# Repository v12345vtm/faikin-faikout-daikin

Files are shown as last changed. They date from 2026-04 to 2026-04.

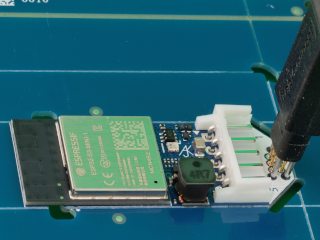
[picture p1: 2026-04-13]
releaseBinaries/Faikout.png

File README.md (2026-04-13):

# faikin-faikout-daikin
ESP32 dev board S1 mode

## 1. Install esptool.py (Windows 10)

**Prerequisites:** Python 3.7+ with pip installed

1. **Open Command Prompt as Administrator**
2. **Install:**
   ```bash
   pip install esptool
   ```
   *Or if needed:*
   ```bash
   python -m pip install esptool
   ```
3. **Test installation:**
   ```bash
   esptool version
   ```
   *Expected: `esptool.py v4.7` (or similar)*

**If "command not found":**
- Add Python Scripts folder to PATH:
  - `C:\Python39\Scripts` or `%APPDATA%\Python\Python39\Scripts`
  - System Properties → Environment Variables → Path → Edit → New → Add path → OK
  - Restart Command Prompt

## 2. Flash Faikout S1 Firmware

1. **Download release binaries** to a folder (all 4 `.bin` files):
   - `Faikout-S1-bootloader.bin`
   - `Faikout-S1-partition-table.bin`
   - `Faikout-S1-ota_data_initial.bin`
   - `Faikout-S1.bin`

2. **Navigate to that folder**:
   - Hold `Shift` + right-click in folder
   - "Open PowerShell window here" (or "Open command window here")
   - Type `cmd` and Enter

3. **Connect ESP32 dev board** to USB (check COM port in Device Manager)

4. **Put board in flash mode**:
   - Hold BOOT button
   - Press and release RESET button  
   - Release BOOT button

5. **Flash firmware** (replace COM3 with your port):
   ```bash
   python -m esptool -p COM3 write_flash ^
   0x1000 Faikout-S1-bootloader.bin ^
   0x8000 Faikout-S1-partition-table.bin ^
   0xD000 Faikout-S1-ota_data_initial.bin ^
   0x10000 Faikout-S1.bin
   ```

6. **Home Assistant**:
   - use the official integration Daikin for the faikin-faikout
   - or esphome alternative = https://github.com/joshbenner/esphome-daikin-s21 where the mosfets will not be needed but has some less features
 
7. **S10 portt**:
   - set rx tc in the esp32 webinterface
   - the original board uses fets to drive the S10 port ( maybe its inverted ?)
   - The physical interface is basic serial data, low is 0, high is 1. However the Daikin appears to operate with a 5V internal pull up on Tx and Rx lines, and a pull down. The Faikout uses a FET each way, which means internally the lines are inverted.
   - so use
   - Use a simple MOSFET level shifter:
   - BSS138 (very common)👉 This matches what RevK boards do
   - 2x pull-up resistors (e.g. 10k)

The S403 port is a non-isolated S21 port, i.e. it is at MAINS POWER levels, and dangerous. Any connected device, such as a Faikout, needs to be inside the case.

The S21 port pin out is 1:1 the same as the Faikout pin out :-
   
## 3. Troubleshooting

- **Wrong COM port?** Device Manager → Ports (COM & LPT)
- **Drivers missing?** Install CP210x/CH340 drivers
- **Connection fails?** 
  - Run CMD as Administrator
  - Add `--baud 115200` to command
  - Try different USB cable/port

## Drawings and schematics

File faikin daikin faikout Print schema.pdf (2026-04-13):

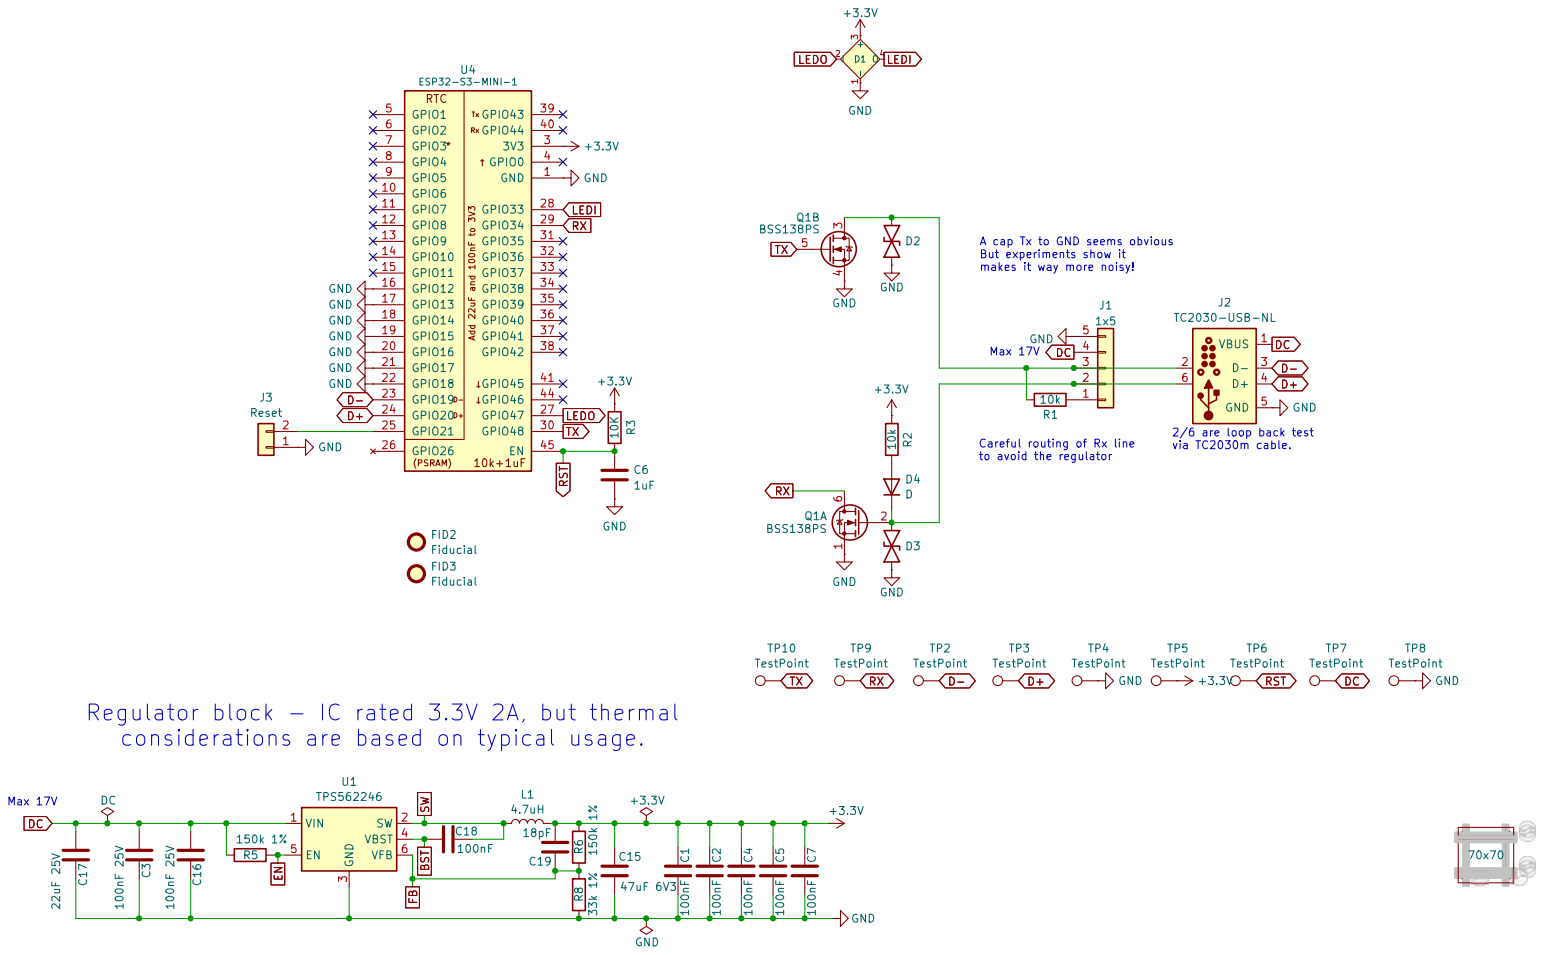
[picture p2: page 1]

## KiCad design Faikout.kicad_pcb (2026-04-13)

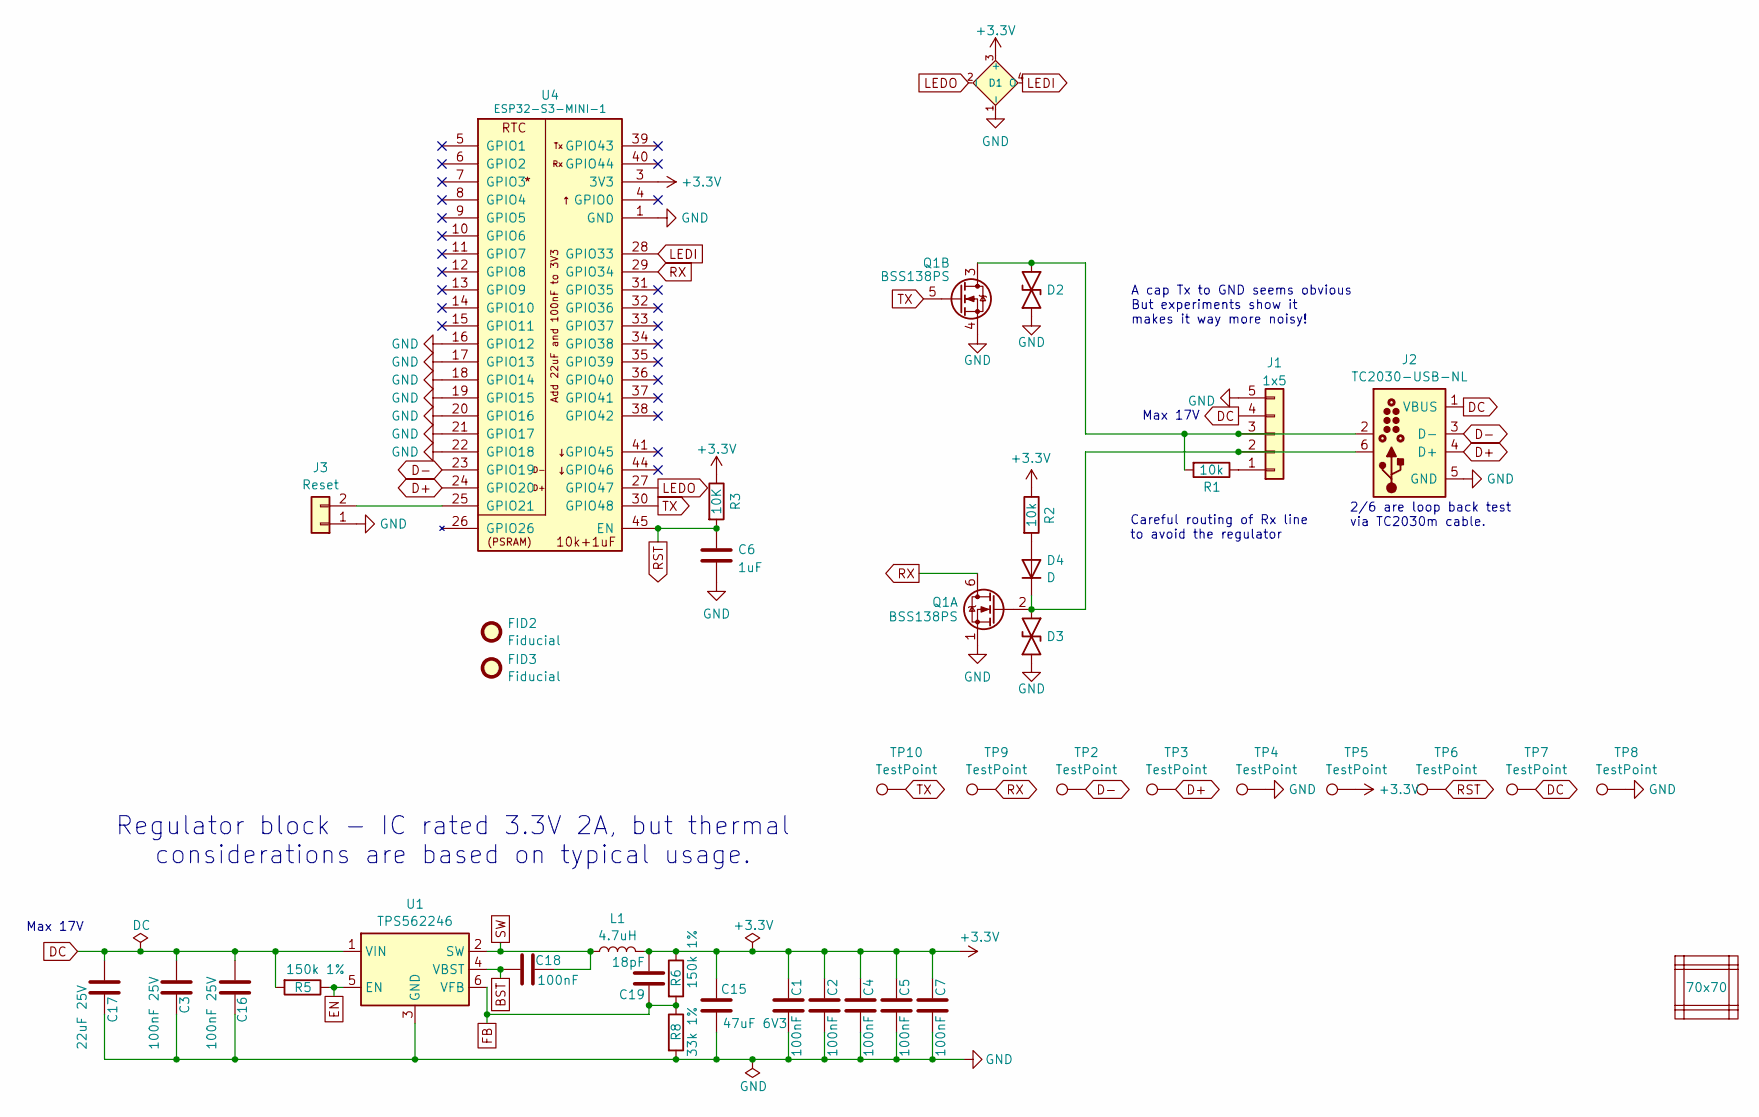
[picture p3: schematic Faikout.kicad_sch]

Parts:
C1, C2, C4, C5, C7, C18: 100nF; C_0201; MPN C76934
C3, C16: 100nF 25V; C_0402; MPN C56392
C6: 1uF; C_0201
C15: 47uF 6V3; C_0805; MPN C16780
C17: 22uF 25V; C_0805; MPN C45783
C19: 18pF; C_0201; MPN C62164
D1: XL-1615RGBC-2812B; SMD1615; MPN C5349954
D2, D3: DFN1006-2L; MPN C5137770
D4: D; D_0402; MPN C28642302
FID2, FID3: Fiducial; Fiducial_1mm_Mask2mm
J1: 1x5; JST_EH_S5B-EH_1x05_P2.50mm_Horizontal; MPN C265103
J2: TC2030-USB-NL; Tag-Connect_TC2030-IDC-NL_2x03_P1.27mm_Vertical
J3: Reset; AA-Pad
L1: 4.7uH; L_5x5; MPN C307876
PCB1: 70x70; PCB7070
Q1: BSS138PS; SOT-363_SC-70-6; MPN C193381
R1, R2: 10k; R_0201; MPN C106225
R3: 10K; R_0201; MPN C106225
R5, R6: 150k 1%; R_0201; MPN C310173
R8: 33k 1%; R_0201; MPN C320835
TP2, TP3, TP4, TP5, TP6, TP7, TP8, TP9, TP10: TestPoint; PAD-2mm
U1: TPS562246; SOT-5x3-6; MPN C41833479
U4: ESP32-S3-MINI-1; MPN C3013941
V1, V2, V3, V4, V5, V6: VCUT70N

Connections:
+3.3V: C1.2, C2.2, C4.2, C5.2, C7.2, C15.1, C19.2, D1.3 (+), L1.2, R2.1, R3.1, R6.1, TP5.1, U4.3 (3V3)
BST: C18.1, U1.4 (VBST)
D+: J2.4 (D+), TP3.1, U4.24 (GPIO20)
D-: J2.3 (D-), TP2.1, U4.23 (GPIO19)
DC: C3.1, C16.1, C17.1, J1.4, J2.1 (VBUS), R5.2, TP7.1, U1.1 (VIN)
EN: R5.1, U1.5 (EN)
FB: C19.1, R6.2, R8.1, U1.6 (VFB)
GND: C1.1, C2.1, C3.2, C4.1, C5.1, C6.2, C7.1, C15.2, C16.2, C17.2, D1.1 (-), D2.1, D3.1, J1.5, J2.5 (GND), J3.1, Q1.1 (SN), Q1.4 (DP), R8.2, TP4.1, TP8.1, U1.3 (GND), U4.1 (GND), U4.2 (GND), U4.16 (GPIO12), U4.17 (GPIO13), U4.18 (GPIO14), U4.19 (GPIO15), U4.20 (GPIO16), U4.21 (GPIO17), U4.22 (GPIO18), U4.42 (GND), U4.43 (GND), U4.46 (GND), U4.47 (GND), U4.48 (GND), U4.49 (GND), U4.50 (GND), U4.51 (GND), U4.52 (GND), U4.53 (GND), U4.54 (GND), U4.55 (GND), U4.56 (GND), U4.57 (GND), U4.58 (GND), U4.59 (GND), U4.60 (GND), U4.61 (GND), U4.62 (GND), U4.63 (GND), U4.64 (GND), U4.65 (GND)
LEDI: D1.4 (O), U4.28 (GPIO33)
LEDO: D1.2 (I), U4.27 (GPIO47)
unnamed: D4.2 (A), R2.2
unnamed: D3.2, D4.1 (K), J1.2, J2.6, Q1.2 (GN)
unnamed: J1.1, R1.1
unnamed: D2.2, J1.3, J2.2, Q1.3 (SP), R1.2
unnamed: J3.2, U4.25 (GPIO21)
RST: C6.1, R3.2, TP6.1, U4.45 (EN)
RX: Q1.6 (DN), TP9.1, U4.29 (GPIO34)
SW: C18.2, L1.1, U1.2 (SW)
TX: Q1.5 (GP), TP10.1, U4.30 (GPIO48)

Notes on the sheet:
Max 17V
Careful routing of Rx line to avoid the regulator
2/6 are loop back test via TC2030m cable.
A cap Tx to GND seems obvious But experiments show it makes it way more noisy!
Regulator block - IC rated 3.3V 2A, but thermal considerations are based on typical usage.

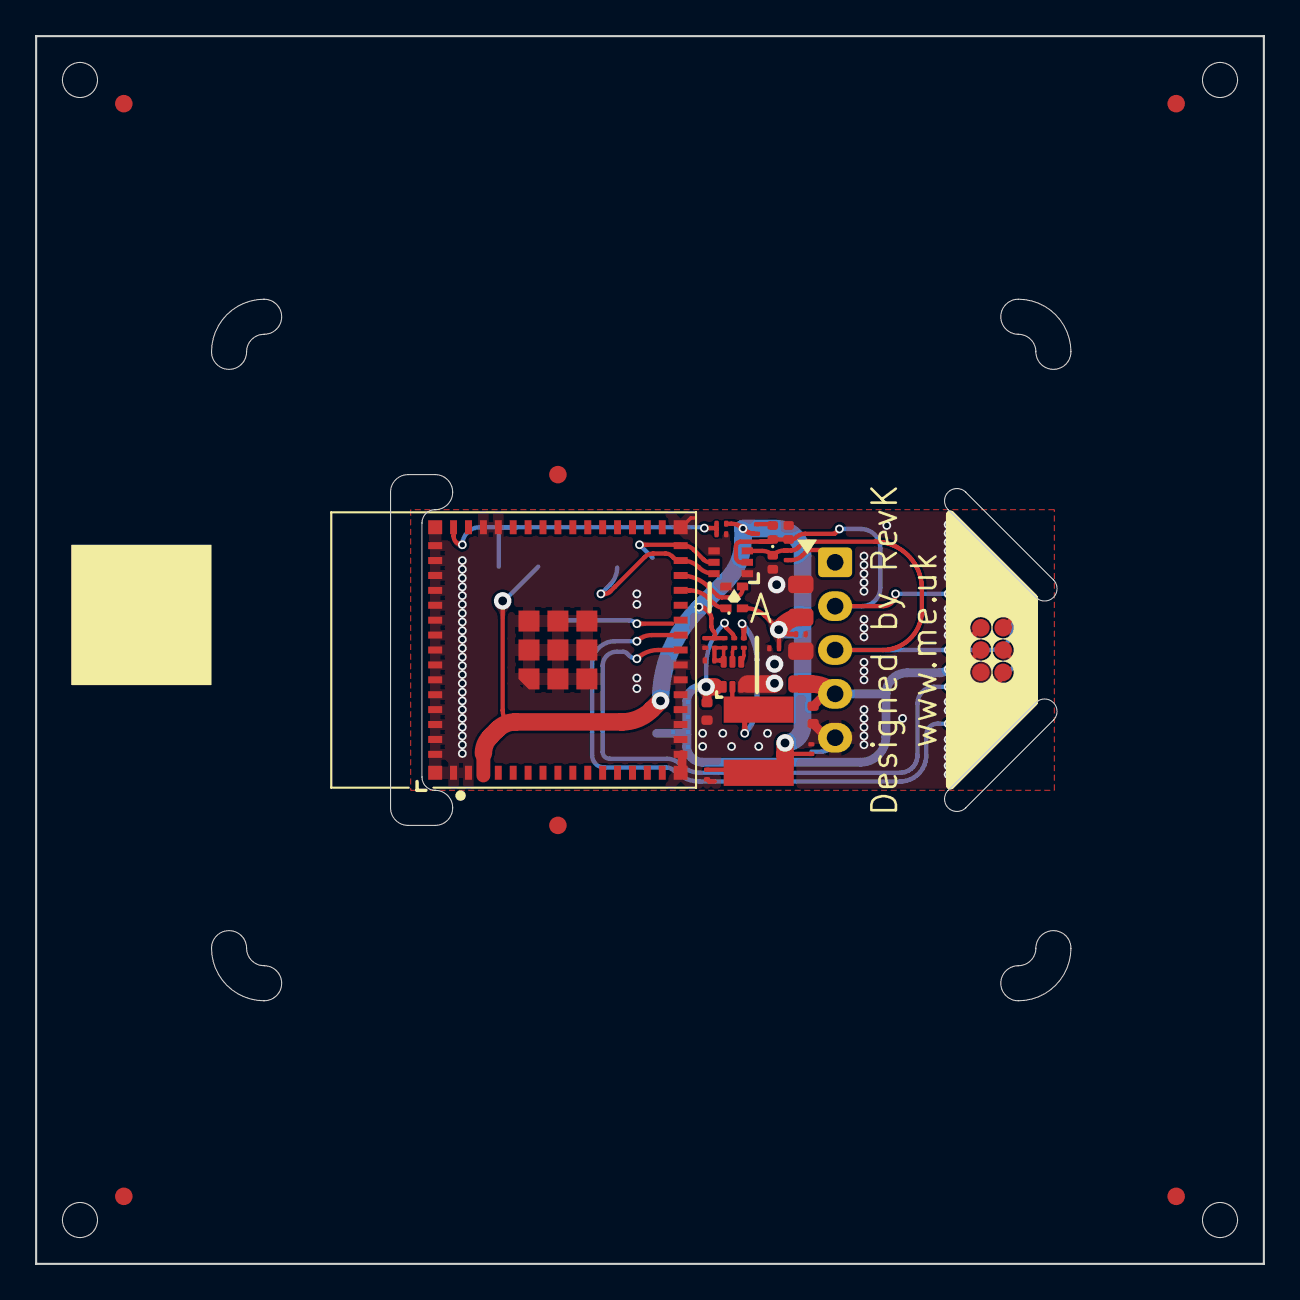
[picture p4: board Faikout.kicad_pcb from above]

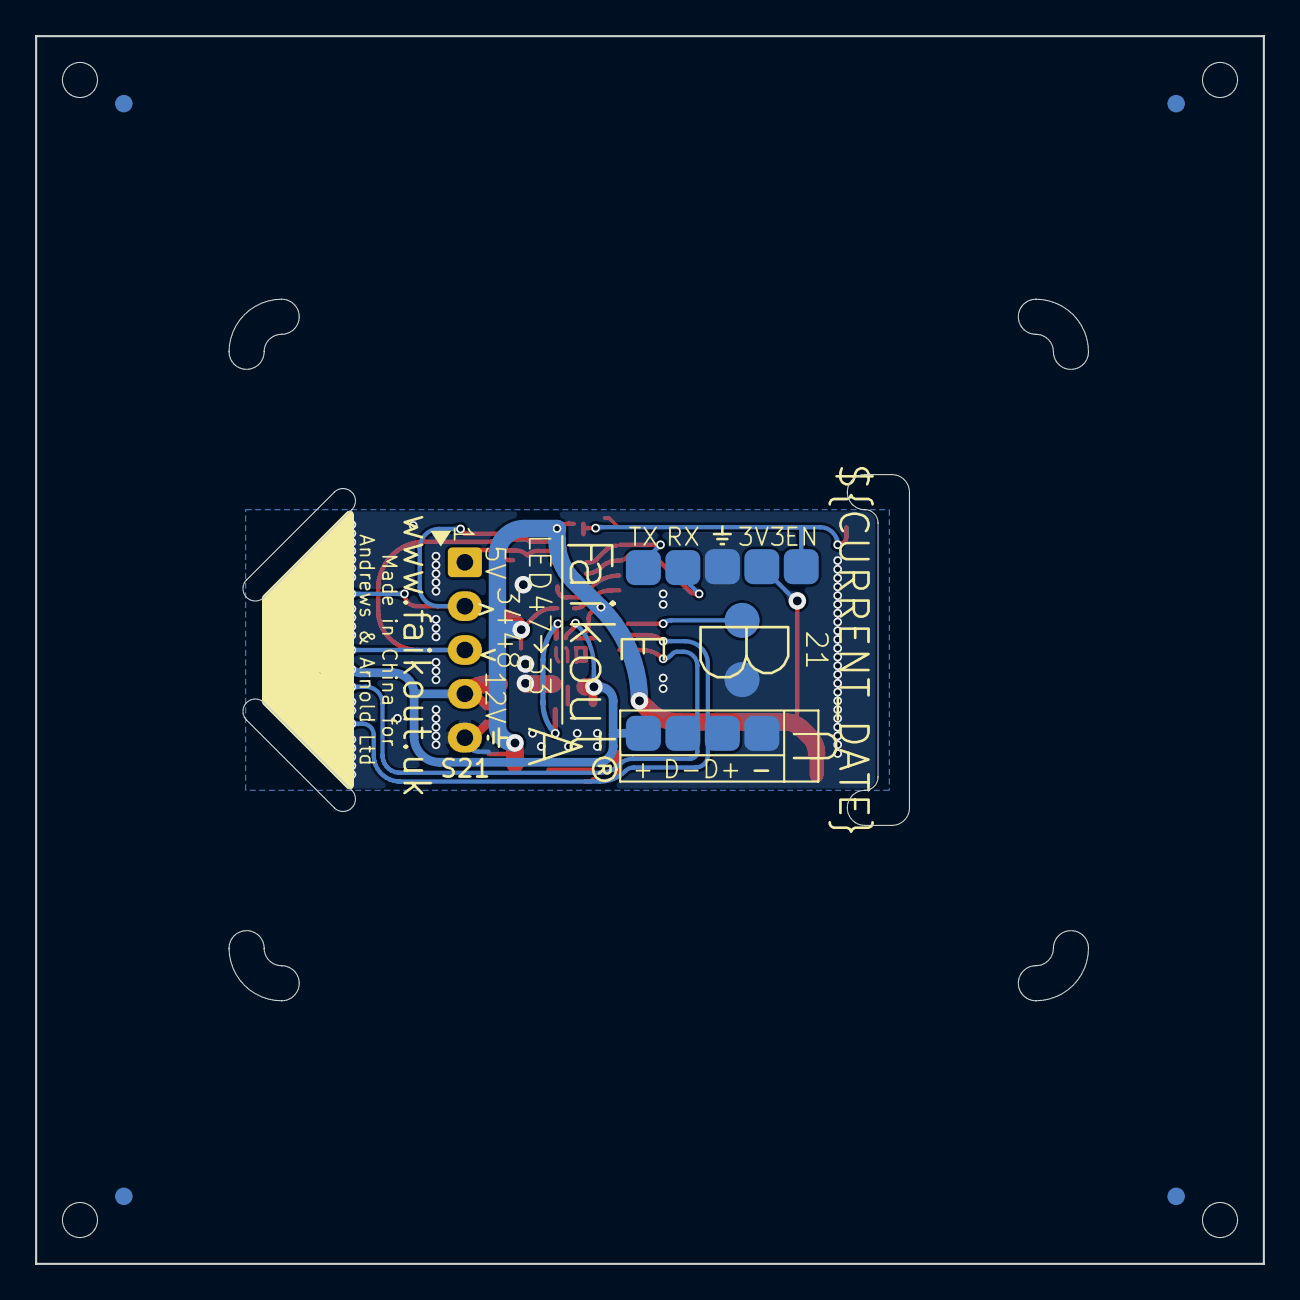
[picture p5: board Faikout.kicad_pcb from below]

Board: 2 copper layers, 70.0 x 70.0 mm, 47 parts (12 on the bottom side), 19 nets.

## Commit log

2026-04-13 Enhance README with detailed ESP32 setup instructions
    Updated installation and flashing instructions for ESP32 dev board S1 mode, including prerequisites and troubleshooting steps.
2026-04-13 Update S10 port section in README with details
    Clarified S10 port details and added information about MOSFET level shifter requirements.
